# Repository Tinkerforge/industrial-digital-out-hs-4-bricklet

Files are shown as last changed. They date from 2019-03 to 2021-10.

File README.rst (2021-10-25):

Industrial Digital Out HS 4 Bricklet
====================================

**The development of this Bricklet was stopped.**

This repository contains the firmware source code and the hardware design
files. The documentation generator configs can be found at
https://github.com/Tinkerforge/generators

Repository Content
------------------

software/:
 * examples/: Examples for all supported languages
 * build/: Makefile and compiled files
 * src/: Source code of firmware
 * generate_makefile: Shell script to generate Makefile from cmake script

hardware/:
 * Contains kicad project files and additionally schematics as pdf

datasheets/:
 * Contains datasheets for sensors and complex ICs that are used

Hardware
--------

The hardware is designed with the open source EDA Suite KiCad
(http://www.kicad.org). Before you are able to open the files,
you have to install the Tinkerforge kicad-libraries
(https://github.com/Tinkerforge/kicad-libraries). You can either clone
them directly in hardware/ or clone them in a separate folder and
symlink them into hardware/
(ln -s kicad_path/kicad-libraries project_path/hardware). After that you
can open the .pro file in hardware/ with kicad and from there view and
modify the schematics and the PCB layout.

Software
--------

If you want to do your own Brick/Bricklet firmware development we highly
recommend that you use our build environment setup script and read the
tutorial (https://www.tinkerforge.com/en/doc/Tutorials/Tutorial_Build_Environment/Tutorial.html).

To compile the C code we recommend you to install the newest GNU Arm Embedded
Toolchain (https://launchpad.net/gcc-arm-embedded/+download).
You also need to install bricklib2 (https://github.com/Tinkerforge/bricklib2).

You can either clone it directly in software/src/ or clone it in a
separate folder and symlink it into software/src/
(ln -s bricklib_path/bricklib2 project_path/software/src/). Finally make sure to
have CMake installed (http://www.cmake.org/cmake/resources/software.html).

After that you can generate a Makefile from the cmake script with the
generate_makefile shell script (in software/) and build the firmware
by invoking make in software/build/. The firmware (.zbin) can then be found
in software/build/ and uploaded with brickv (click button "Flashing"
on start screen).

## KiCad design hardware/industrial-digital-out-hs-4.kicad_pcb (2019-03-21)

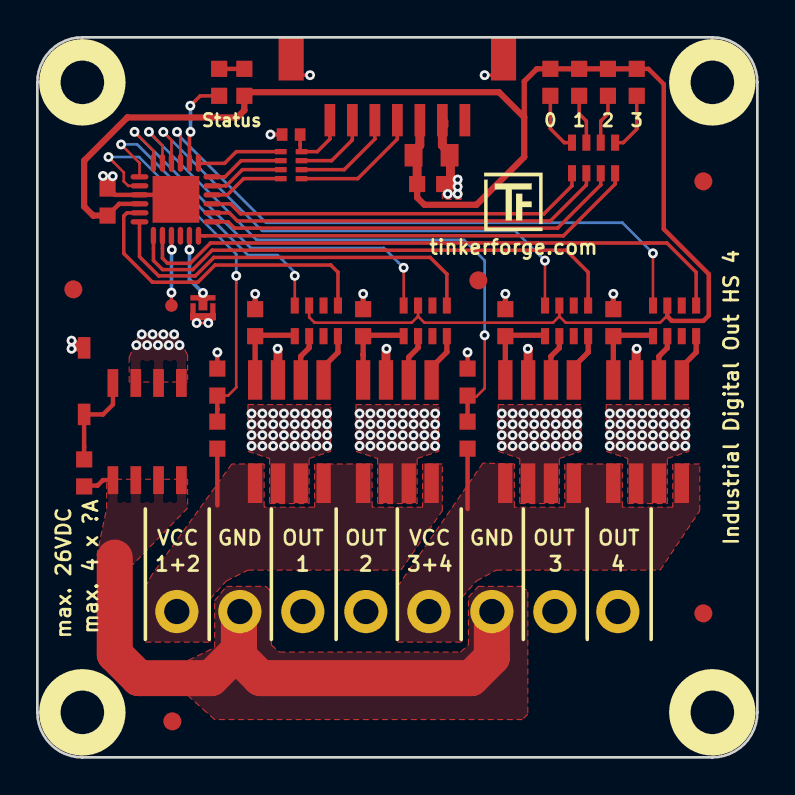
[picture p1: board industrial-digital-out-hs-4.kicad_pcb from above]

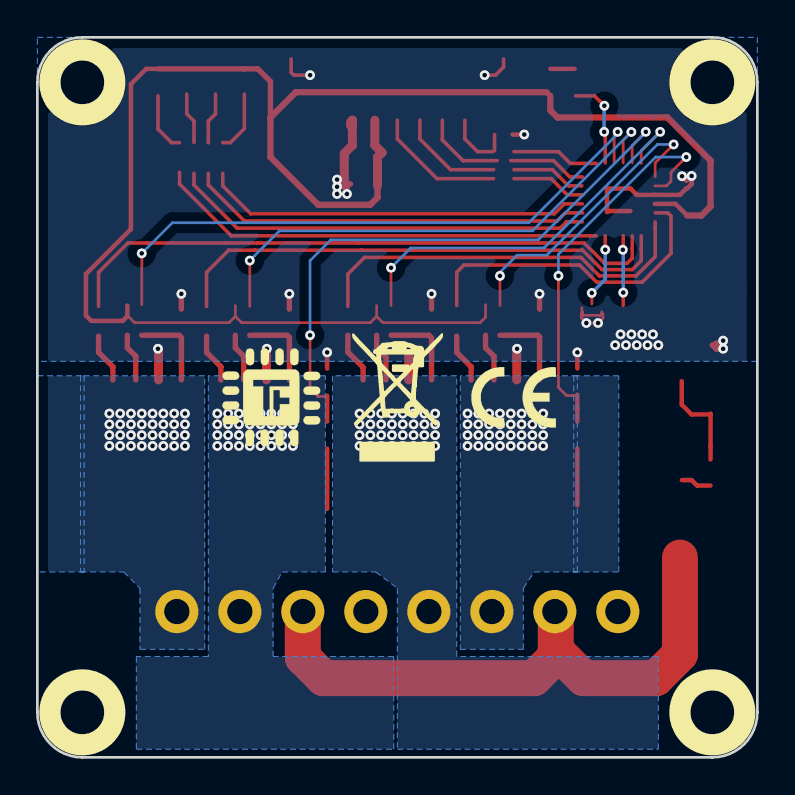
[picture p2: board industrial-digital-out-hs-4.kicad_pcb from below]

Board: 2 copper layers, 40.0 x 40.0 mm, 47 parts (2 on the bottom side), 52 nets.

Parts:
C1, C4: 100nF; C0603F
C2: 220pF; C0402F
C3: 10uF; C0805
D1, D2, D3, D4, D5: blue; D0603F
D6: Z12V; SOD-123
Fiducial_Mark: VAL**; Fiducial_Mark
Fiducial_Mark#2, Fiducial_Mark#3, Fiducial_Mark#4, Fiducial_Mark#5: VAL**; Fiducial_Mark
P1: CON-SENSOR; CON-SENSOR2
P2: Digital Output; OQ_8P
P3: Debug; DEBUG_PAD
P4: Boot; SolderJumper
Q1: FDS8449; SOIC-8-MOSFET
R1, R2, R3, R4, R5, R7, R9: 1k; R0603F
R6, R8: 10k; R0603F
R10: 100k; R0603F
RP1, RP4, RP5, RP6: 10k; 4X0603
RP2: 82; 4X0402
RP3: 1k; 0603X4
U1: XMC1100; QFN24-4x4mm-0.5mm
U2, U3, U4, U5: VN7140AS; SO-8
U6, U7, U8, U9: DRILL; DRILL_NP
VAL: WEEE_7mm
VAL#2: CE_5mm

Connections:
3V3: C1.1, C3.1, C4.1, D1.1, D2.1, D3.1, D4.1, D5.1, P1.3, RP1.2, RP4.2, RP5.2, RP6.2, U1.10
GND: C1.2, C2.2, C3.2, C4.2, D6.1, P1.2, P1.EP, P4.1, Q1.S, R1.2, R2.2, R3.2, R4.2, R7.2, R9.2, U1.9, U1.EXP, U2.3, U3.3, U4.3, U5.3
LED0: RP3.1, U1.21
LED1: RP3.2, U1.20
LED2: RP3.3, U1.19
LED3: RP3.4, U1.18
MSense0: RP6.1, U1.7
MSense1: RP5.1, U1.6
MSense2: RP4.1, U1.4
MSense3: RP1.1, U1.3
unnamed: C2.1, P1.7, RP2.4
unnamed: D1.2, R5.2
unnamed: D2.2, RP3.8
unnamed: D3.2, RP3.7
unnamed: D4.2, RP3.6
unnamed: D5.2, RP3.5
unnamed: D6.2, Q1.G, R10.2
unnamed: P1.4, RP2.1
unnamed: P1.5, RP2.2
unnamed: P1.6, RP2.3
unnamed: P2.1, R8.1, U4.5, U4.8, U5.5, U5.8
unnamed: P2.2, P2.6, Q1.D, R10.1
unnamed: P2.3, U5.6, U5.7
unnamed: P2.4, U4.6, U4.7
unnamed: P2.5, R6.1, U2.5, U2.8, U3.5, U3.8
unnamed: P2.7, U3.6, U3.7
unnamed: P2.8, U2.6, U2.7
unnamed: P3.1, U1.15
unnamed: P4.2, U1.17
unnamed: R1.1, RP1.8, U2.4
unnamed: R2.1, RP4.8, U3.4
unnamed: R3.1, RP5.8, U4.4
unnamed: R4.1, RP6.8, U5.4
unnamed: R5.1, U1.2
unnamed: RP1.5, U2.1
unnamed: RP1.7, U2.2
unnamed: RP4.5, U3.1
unnamed: RP4.7, U3.2
unnamed: RP5.5, U4.1
unnamed: RP5.7, U4.2
unnamed: RP6.5, U5.1
unnamed: RP6.7, U5.2
OUT0: RP6.4, U1.11
OUT1: RP5.4, U1.12
OUT2: RP4.4, U1.13
OUT3: RP1.4, U1.14
S-CLK: RP2.7, U1.23
S-CS: RP2.8, U1.22
S-MISO: RP2.5, U1.1
S-MOSI: RP2.6, U1.24
VSense0: R8.2, R9.1, U1.8
VSense1: R6.2, R7.1, U1.5

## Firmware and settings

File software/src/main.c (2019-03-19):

/* industrial-digital-out-hs-4-bricklet
 * Copyright (C) 2019 Olaf Lüke <olaf@tinkerforge.com>
 *
 * main.c: Initialization for Industrial Digital Out HS 4 Bricklet
 *
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
 * You should have received a copy of the GNU Lesser General Public
 * License along with this library; if not, write to the
 * Free Software Foundation, Inc., 59 Temple Place - Suite 330,
 * Boston, MA 02111-1307, USA.
 */

#include <stdio.h>
#include <stdbool.h>

#include "configs/config.h"

#include "bricklib2/bootloader/bootloader.h"
#include "bricklib2/hal/system_timer/system_timer.h"
#include "bricklib2/logging/logging.h"
#include "communication.h"

#include "ido4.h"
#include "vn7140aj.h"

int main(void) {
	logging_init();
	logd("Start Industrial Digital Out HS 4 Bricklet\n\r");

	communication_init();
	ido4_init();
	vn7140aj_init();

	while(true) {
		bootloader_tick();
		communication_tick();
		ido4_tick();
		vn7140aj_tick();
	}
}

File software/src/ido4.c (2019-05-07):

/* industrial-digital-out-hs-4-bricklet
 * Copyright (C) 2018 Ishraq Ibne Ashraf <ishraq@tinkerforge.com>
 * Copyright (C) 2018-2019 Olaf Lüke <olaf@tinkerforge.com>
 *
 * ido4.h: Implementation of Industrial Digital Out 4 V2 Bricklet
 *
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
 * You should have received a copy of the GNU Lesser General Public
 * License along with this library; if not, write to the
 * Free Software Foundation, Inc., 59 Temple Place - Suite 330,
 * Boston, MA 02111-1307, USA.
 */

#include "ido4.h"

#include <stdint.h>
#include <stdbool.h>

#include "bricklib2/logging/logging.h"
#include "bricklib2/hal/system_timer/system_timer.h"
#include "bricklib2/utility/util_definitions.h"

#include "communication.h"

#include "xmc_ccu4.h"

#include "configs/config_ido4.h"

IDO4_t ido4;

XMC_CCU4_SLICE_t *const ido4_slice[NUMBER_OF_CHANNELS] = {
	CCU40_CC43,
	CCU40_CC42,
	CCU40_CC41,
	CCU40_CC40,
};

void ido4_pwm_stop(const uint8_t channel) {
#if 0
	if(ido4.channels[channel].pwm.frequency != 0) {
		ido4.channels[channel].pwm.duty_cycle = 0;
		ido4.channels[channel].pwm.frequency  = 0;
		XMC_CCU4_SLICE_StopTimer(ido4_slice[channel]);

		const XMC_GPIO_CONFIG_t pwm_stop_config	= {
			.mode                = XMC_GPIO_MODE_OUTPUT_PUSH_PULL,
			.input_hysteresis    = XMC_GPIO_INPUT_HYSTERESIS_STANDARD,
			.output_level        = XMC_GPIO_OUTPUT_LEVEL_LOW,
		};

		XMC_GPIO_Init(ido4.channels[channel].port, ido4.channels[channel].pin, &pwm_stop_config);
	}
#endif
}

void ido4_pwm_init(const uint8_t channel) {
#if 0
	const XMC_CCU4_SLICE_COMPARE_CONFIG_t compare_config = {
		.timer_mode          = XMC_CCU4_SLICE_TIMER_COUNT_MODE_EA,
		.monoshot            = false,
		.shadow_xfer_clear   = 0,
		.dither_timer_period = 0,
		.dither_duty_cycle   = 0,
		.prescaler_mode      = XMC_CCU4_SLICE_PRESCALER_MODE_NORMAL,
		.mcm_enable          = 0,
		.prescaler_initval   = 0,
		.float_limit         = 0,
		.dither_limit        = 0,
		.passive_level       = XMC_CCU4_SLICE_OUTPUT_PASSIVE_LEVEL_LOW,
		.timer_concatenation = 0
	};

	const XMC_GPIO_CONFIG_t pwm_config	= {
		.mode                = XMC_GPIO_MODE_OUTPUT_PUSH_PULL_ALT2,
		.input_hysteresis    = XMC_GPIO_INPUT_HYSTERESIS_STANDARD,
		.output_level        = XMC_GPIO_OUTPUT_LEVEL_LOW,
	};

	XMC_CCU4_Init(CCU40, XMC_CCU4_SLICE_MCMS_ACTION_TRANSFER_PR_CR);
	XMC_CCU4_StartPrescaler(CCU40);
	XMC_CCU4_SLICE_CompareInit(ido4_slice[channel], &compare_config);

	// Set the period and compare register values
	XMC_CCU4_SLICE_SetTimerPeriodMatch(ido4_slice[channel], 32000);
	XMC_CCU4_SLICE_SetTimerCompareMatch(ido4_slice[channel], 0);

	XMC_CCU4_EnableShadowTransfer(CCU40, (XMC_CCU4_SHADOW_TRANSFER_SLICE_0 << (ido4.channels[channel].pin*4)) |
	                                     (XMC_CCU4_SHADOW_TRANSFER_PRESCALER_SLICE_0 << (ido4.channels[channel].pin*4)));

	XMC_GPIO_Init(ido4.channels[channel].port, ido4.channels[channel].pin, &pwm_config);

	XMC_CCU4_EnableClock(CCU40, ido4.channels[channel].pin);
#endif
}

void ido4_pwm_update(const uint8_t channel, const uint32_t frequency, const uint16_t duty_cycle) {
#if 0
	if(frequency == 0) {
		ido4_pwm_stop(channel);
		return;
	}

	const bool new_start = ido4.channels[channel].pwm.frequency == 0;

	if(new_start) {
		ido4_pwm_init(channel);
	}

	ido4.channels[channel].pwm.duty_cycle = MIN(10000, duty_cycle);
	ido4.channels[channel].pwm.frequency  = MIN(320000000, frequency);

	uint32_t prescaler = 0;
	uint32_t divisor = 1;
	uint32_t period_value = (640000000/ido4.channels[channel].pwm.frequency) - 1;
	while(period_value > 0xFFFF) {
		prescaler++;
		divisor *= 2;
		period_value = (640000000/(ido4.channels[channel].pwm.frequency*divisor)) - 1;
	}

	uint32_t compare_value = (period_value*duty_cycle + 10000/2)/10000;

	XMC_CCU4_SLICE_SetPrescaler(ido4_slice[channel], prescaler);
	XMC_CCU4_SLICE_SetTimerPeriodMatch(ido4_slice[channel], period_value);
	XMC_CCU4_SLICE_SetTimerCompareMatch(ido4_slice[channel], compare_value);
	XMC_CCU4_EnableShadowTransfer(CCU40, (XMC_CCU4_SHADOW_TRANSFER_SLICE_0 << (ido4.channels[channel].pin*4)) |
    		                             (XMC_CCU4_SHADOW_TRANSFER_PRESCALER_SLICE_0 << (ido4.channels[channel].pin*4)));

	if(new_start) {
    	XMC_CCU4_SLICE_StartTimer(ido4_slice[channel]);
	}
#endif
}

void ido4_init(void) {
	memset(&ido4, 0, sizeof(IDO4_t));
	ido4.channels[0].pin  = IDO4_OUT0_PIN;
	ido4.channels[0].port = IDO4_OUT0_PORT;
	ido4.channels[1].pin  = IDO4_OUT1_PIN;
	ido4.channels[1].port = IDO4_OUT1_PORT;
	ido4.channels[2].pin  = IDO4_OUT2_PIN;
	ido4.channels[2].port = IDO4_OUT2_PORT;
	ido4.channels[3].pin  = IDO4_OUT3_PIN;
	ido4.channels[3].port = IDO4_OUT3_PORT;

	ido4.channels[0].status_led.port = IDO4_LED0_PORT;
	ido4.channels[0].status_led.pin  = IDO4_LED0_PIN;
	ido4.channels[1].status_led.port = IDO4_LED1_PORT;
	ido4.channels[1].status_led.pin  = IDO4_LED1_PIN;
	ido4.channels[2].status_led.port = IDO4_LED2_PORT;
	ido4.channels[2].status_led.pin  = IDO4_LED2_PIN;
	ido4.channels[3].status_led.port = IDO4_LED3_PORT;
	ido4.channels[3].status_led.pin  = IDO4_LED3_PIN;

	// Channel out config
	XMC_GPIO_CONFIG_t ch_pin_out_config = {
		.mode         = XMC_GPIO_MODE_OUTPUT_PUSH_PULL,
		.output_level = XMC_GPIO_OUTPUT_LEVEL_LOW,
	};

	// Initialise all the channels
	for(uint8_t i = 0; i < NUMBER_OF_CHANNELS; i++) {
		// Generic channel config

		ido4.channels[i].value = false;

		XMC_GPIO_Init(ido4.channels[i].port, ido4.channels[i].pin, &ch_pin_out_config);

		// Channel monoflop config
		ido4.channels[i].monoflop.time = 0;
		ido4.channels[i].monoflop.time_start = 0;
		ido4.channels[i].monoflop.time_remaining = 0;
		ido4.channels[i].monoflop.running = false;

		XMC_GPIO_Init(ido4.channels[i].status_led.port, ido4.channels[i].status_led.pin, &ch_pin_out_config);
	
		ido4.channels[i].status_led.config = \
			(uint8_t)INDUSTRIAL_DIGITAL_OUT_HS_4_CHANNEL_LED_CONFIG_SHOW_CHANNEL_STATUS;
		ido4.channels[i].status_led.channel_led_flicker_state.config = \
			(uint8_t)LED_FLICKER_CONFIG_OFF;
	}

	// Monopflop callback ringbuffer init
	ringbuffer_init(&ido4.monoflop_cb_rb,
	                MONOFLOP_CB_BUFFER_SIZE,
	                &ido4.monoflop_cb_buffer[0]);
}
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

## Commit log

2019-02-28 added schematic
    [industrial-digital-out-hs-4.sch]
2019-02-28 first pcb powerside layout
    [industrial-digital-out-hs-4.kicad_pcb, industrial-digital-out-hs-4.sch]
2019-03-01 updated pcb design
    [industrial-digital-out-hs-4.kicad_pcb, industrial-digital-out-hs-4.sch]
2019-03-01 first finished prototype design
    [industrial-digital-out-hs-4.kicad_pcb]
2019-03-01 drc check
    [industrial-digital-out-hs-4.kicad_pcb]
2019-03-19 Add initial version of firmware
    This is mostly copied from Industrial Digital Out 4 Bricklet 2.0 with
    additional support for CN7140AJ ADC measurements.
    [cmake_config_custom.txt]
2019-03-21 changed out pins to enable pwm, changed pcb design, plotted gerber files for prototype
    [industrial-digital-out-hs-4.kicad_pcb, industrial-digital-out-hs-4.sch]
2021-10-25 Update KiCad link
    https://www.kicad.org/blog/2021/10/Avoid-links-to-former-kicad-domain/

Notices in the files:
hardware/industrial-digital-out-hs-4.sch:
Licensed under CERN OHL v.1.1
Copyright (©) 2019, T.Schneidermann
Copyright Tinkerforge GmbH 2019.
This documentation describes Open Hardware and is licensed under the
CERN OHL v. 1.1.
